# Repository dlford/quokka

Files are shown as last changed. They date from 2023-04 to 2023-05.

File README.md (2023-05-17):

# Quokka Keyboard

Quokka Keyboard PCB

## Features

- Designed for smaller handed folks
  - Steep columnar stagger
  - Slightly tucked in thumb cluster
- Per-key RGB Matrix using the easier to solder SK6812-MINI-E LEDs
- Piezo speakers
- 128x64 OLED displays
- TRRS jack faces back to keep your cables out of the way
- Full duplex serial connection between halves

## Parts List

**\* Affiliate Links**

- 36x MX keys
- 36x [Kailh MX Hot Swap Sockets](https://amzn.to/3pdbQfA)\*
- 36x [D_0805 1N4148 Diodes](https://amzn.to/3pfWarV)\*
- 2x [PJ-320A TRRS Jacks](https://amzn.to/3NHV4iI)\*
- 2x [Adafruit KB2040 MCU](https://www.adafruit.com/product/5302)
- 8x [Stick-on Rubber Feet](https://amzn.to/3HISXHJ)\*
- 2x [PTS636 SP43 LFS Reset Buttons](https://www.digikey.com/en/products/detail/c-k/PTS636-SP43-LFS/10071717) (Optional)
- 36x [SK6812-MINI-E RGB LEDs](https://www.diykeyboards.com/parts/product/sk6812-mini-e-rgb-led) (Optional)
- 2x [GME12864-49 OLED Displays](https://www.littlekeyboards.com/products/128x64-oled-screen) (Optional)
- 2x [KLJ-1102 Piezo Speakers](https://keeb.io/collections/diy-parts/products/piezo-speaker) (Optional)
- [Pin header strip sockets](https://amzn.to/3VFhROo)\* (Recommended, for hot swapping MCUs/OLEDs)
  - Through hole resistors or diodes to sacrifice legs for pin header strip sockets (if using)
- OLED hardware
  - 16x M2x4mm screws
  - 4x M2x10mm stand-offs for OLED mounting
  - 4x M2x15mm stand-offs for OLED covers
- 3D Printed Case hardware
  - 10x M2x9mm screws
  - 10x [M2x3mm heat set inserts](https://www.mcmaster.com/97163A146/)
- Plated Case hardware
  - 20x M2x4mm screws
  - 10x M2x8mm round stand-offs for plate cases ([these stand-offs](https://amzn.to/42FXkLX)\* fit in a 1/8" hole, don't forget a drill and 1/8" drill bit)

## Build Guide

Download the necessary assets from the [releases](https://github.com/dlford/quokka/releases) page, you will find instructions on producing parts there as well.

1.  Lay out two PCBs, make sure one is flipped, as if you were to type on the keyboard.

    \*Note: if you intend to use plates for the case, you will need to carefully drill out the 5 mounting holes on each PCB (marked in green) with a 1/8" drill bit so the stand-offs can fit through the holes (do not drill out the OLED or OLED cover mounting holes marked in red).

    PCB mounting holes to drill out for plated case

2.  Tin SMD Pads

    Add a bit of solder to on leg of the diodes, switches, and LEDs (if using)

    When soldering SMD components, line up the part close to it's mounting place, heat up the solder on the pre-tinned pad, then slide the part in place, hold it there until after solder is cooled (tweezers will help with smaller parts), then solder the remaining legs, and go back over the first leg to ensure a good connection.

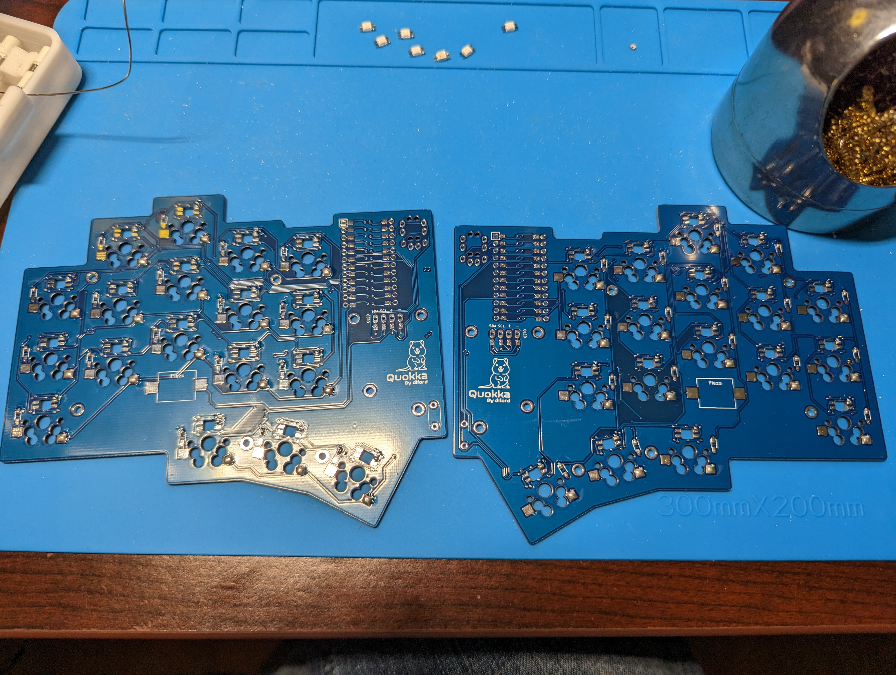
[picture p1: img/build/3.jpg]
SMD Pads Tinned
    

3.  Solder LEDs (if using)

    Place the LEDs _face down_ in the square holes, match the leg with a notch in it to the white triangle on the PCB

    LED orientation, the leg with a notch cut into it matches with the white triangle on the PCB

    LEDs soldered in place

4.  Solder Diodes

    Place the diodes with the stripe facing the top of the keyboard (opposite the thumb keys)

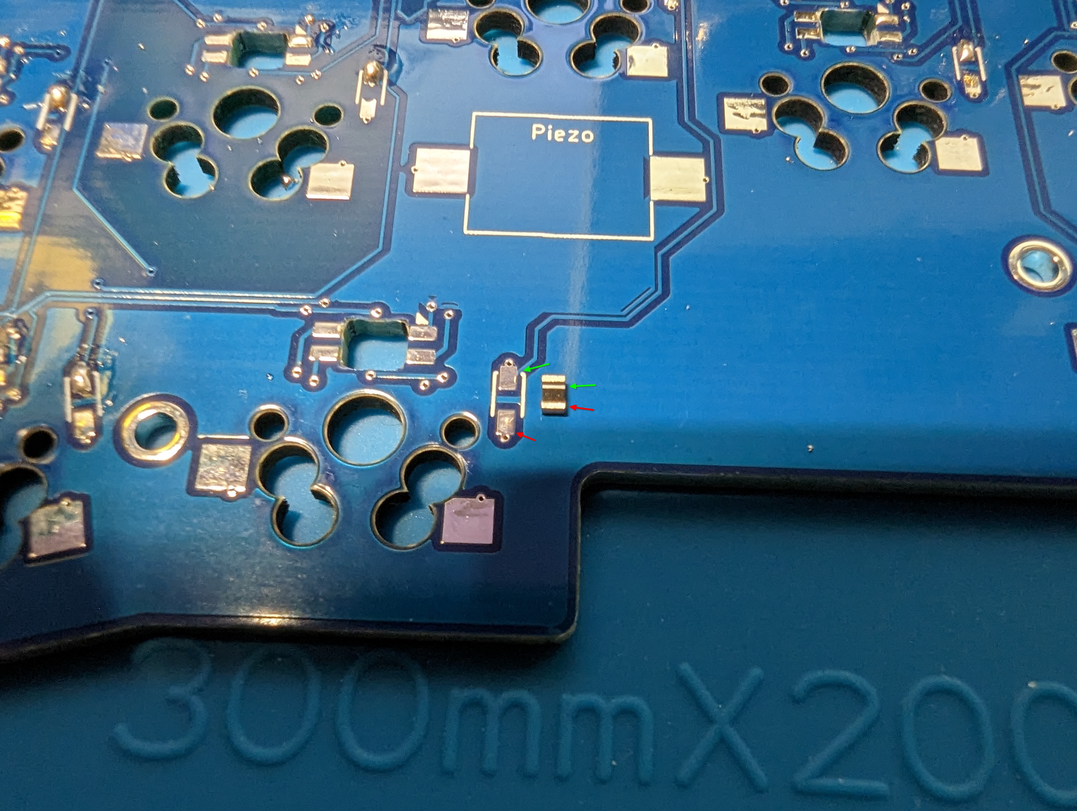
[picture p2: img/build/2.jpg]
Diode orientation
    

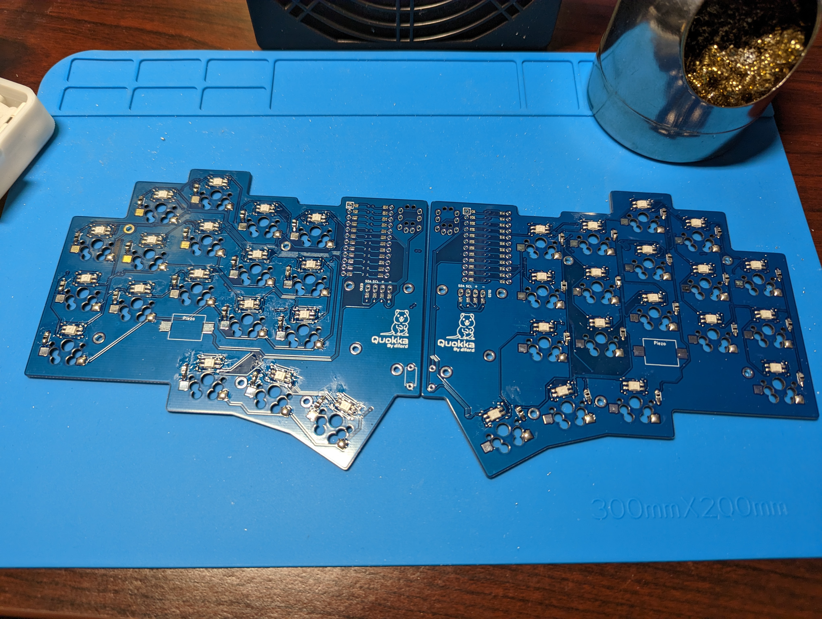
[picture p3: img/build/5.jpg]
Diodes soldered in place
    

5.  Solder Hot Swap Sockets

    Place the sockets so the curved portion is on the left, so as not to cover the center hole for the switch pin

    Hot swap socket orientation

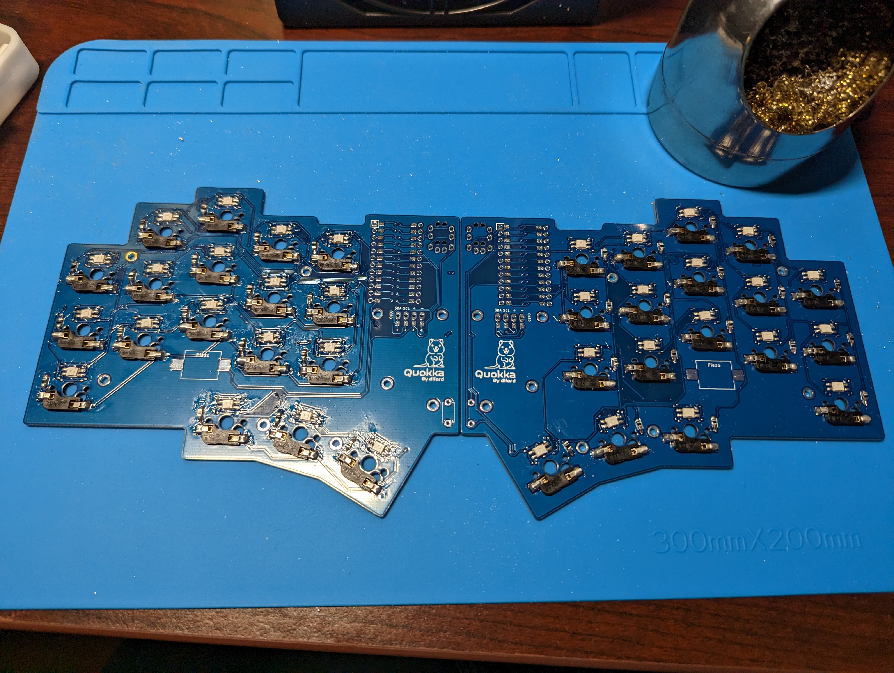
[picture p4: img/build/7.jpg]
Hot swap sockets soldered in place
    

6.  Flip the PCBs over, so everything you just soldered on is on the back, facing the table

7.  Solder the jumpers for the MCU and OLED (if using)

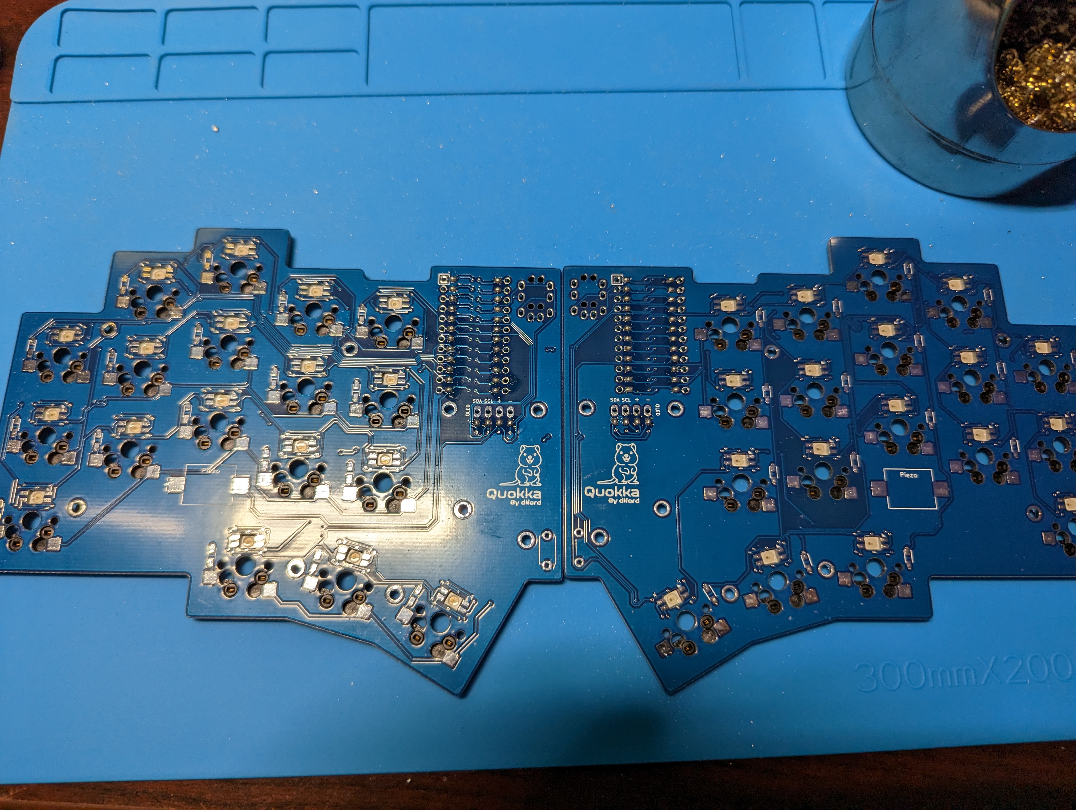
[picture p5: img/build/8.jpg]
Jumpers soldered
    

8.  Solder the TRRS jacks

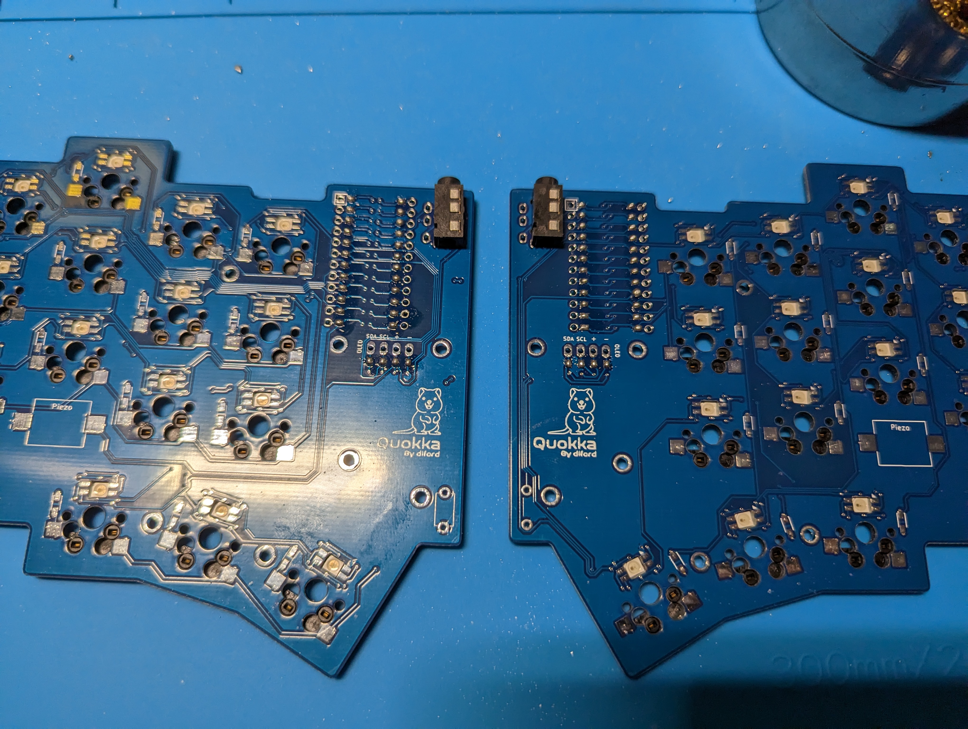
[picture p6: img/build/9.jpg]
TRRS jacks soldered
    

9.  Solder the reset switches

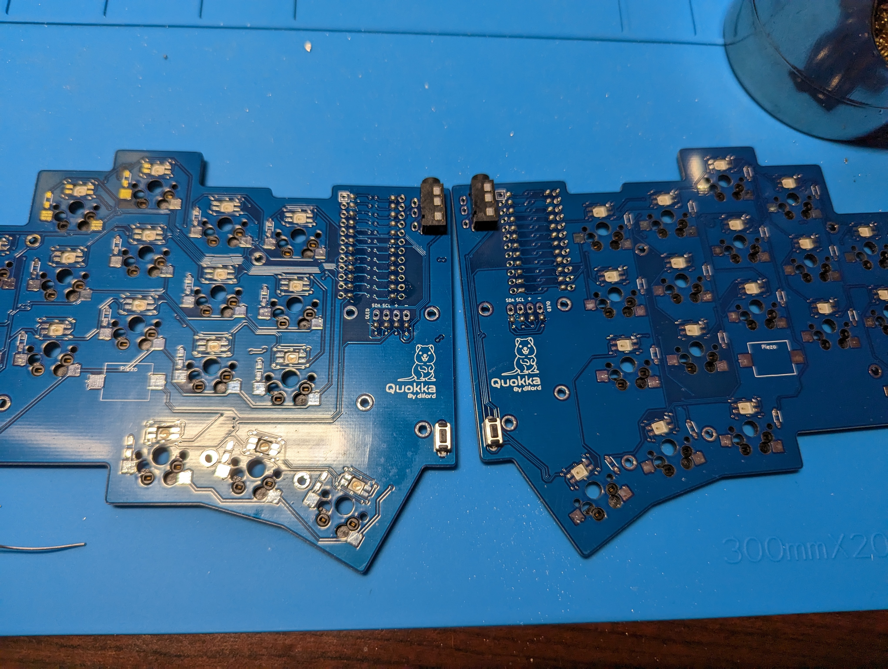
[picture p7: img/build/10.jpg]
Reset switches soldered
    

10. Solder the piezo elements (if using)

    The orientation of piezo elements does not matter

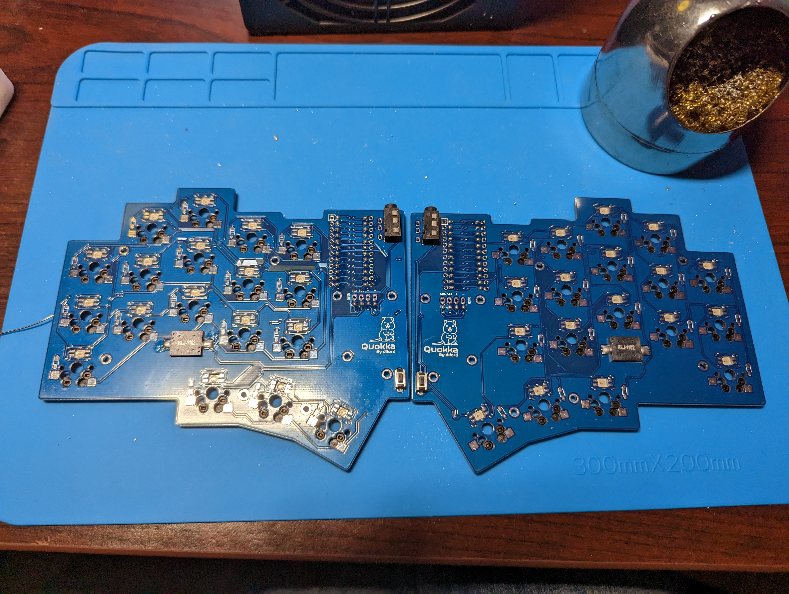
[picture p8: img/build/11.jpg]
Piezo elements soldered
    

11. Solder the header strip sockets for the MCU and OLED (if using)

    After soldering the first leg, heat it back up and adjust the angle of the strip to be as close to vertical as possible

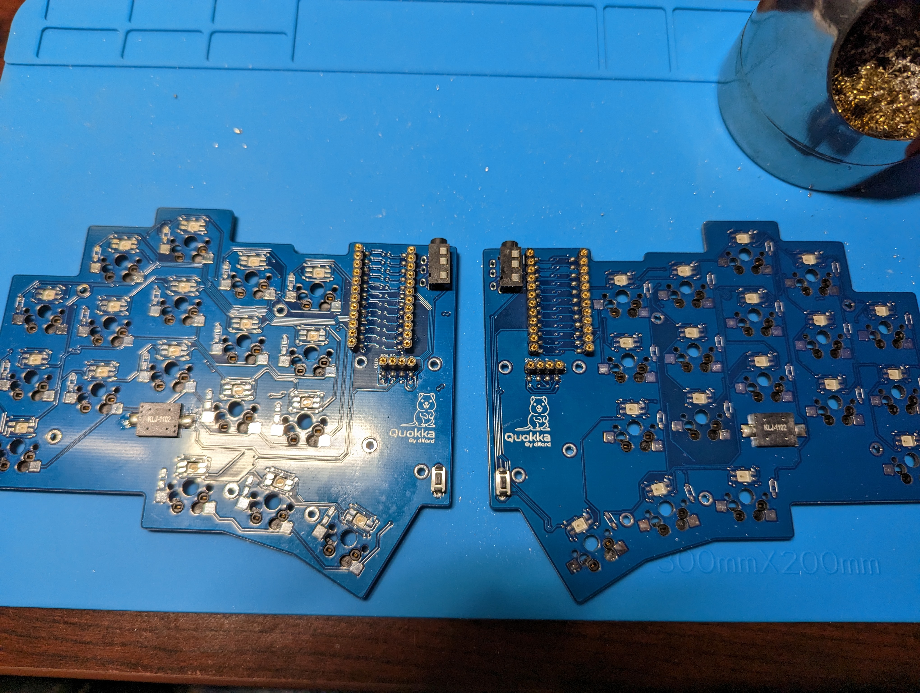
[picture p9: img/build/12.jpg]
Header strip sockets soldered
    

12. Place the MCUs

    Orient the MCUs so they are face up, with the USB-C port facing the back of the keyboard (opposite the thumb keys)

    Use through hole diode or resistor legs to pin down the four corners of each MCU, you should feel some resistance before they drop into the socket, then they will feel snug. Solder down the four corners first.

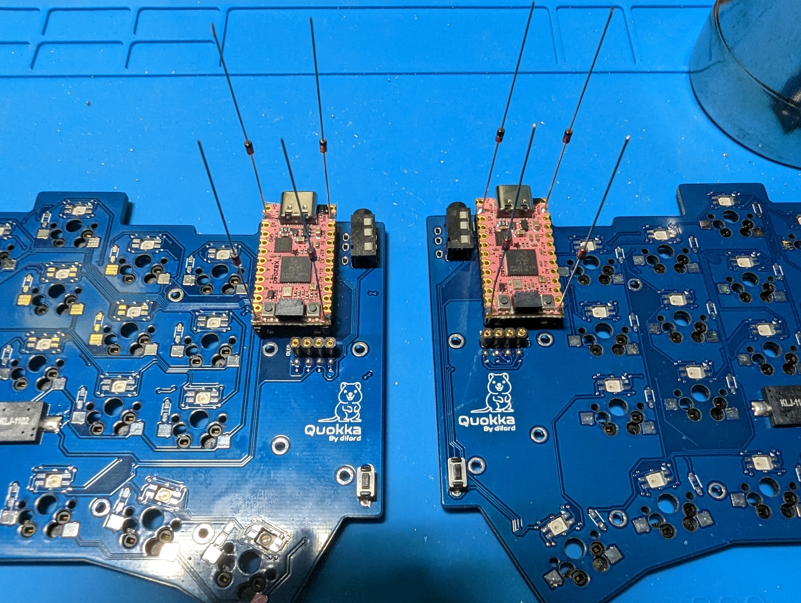
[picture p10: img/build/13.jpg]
MCUs placed
    

    Note that the two contacts closest to the USB-C port on the KB2040 are not used here (also, you may paint black over the power LEDs like I did here, they are quite bright)

    MCU unused contacts

    Cut the diode or resistor legs above the solder joint, and continue soldering each leg the same way

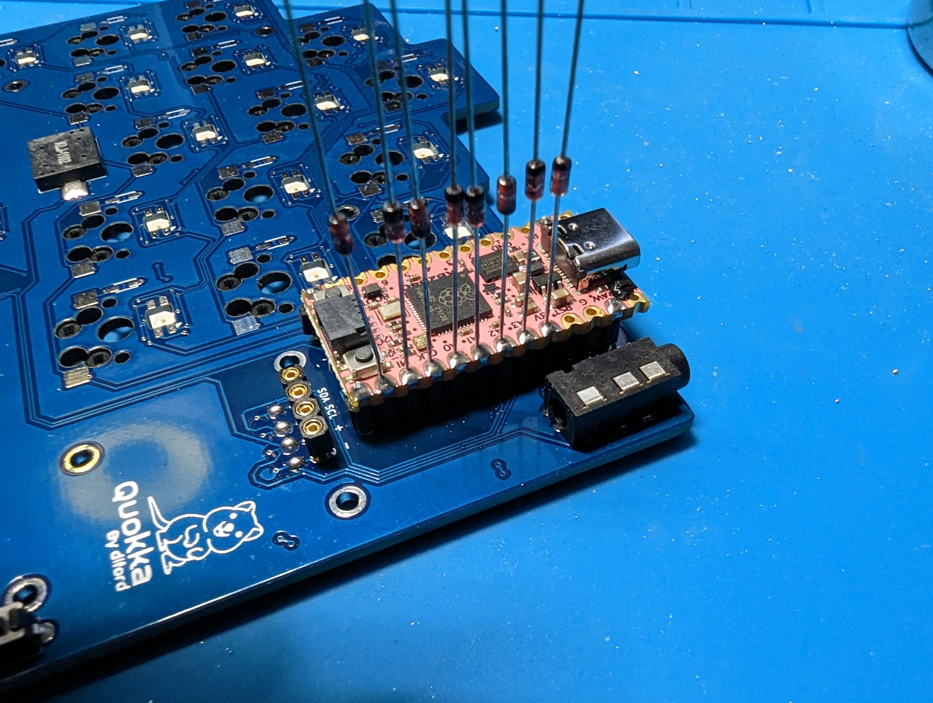
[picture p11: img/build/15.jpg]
MCU contacts soldering process
    

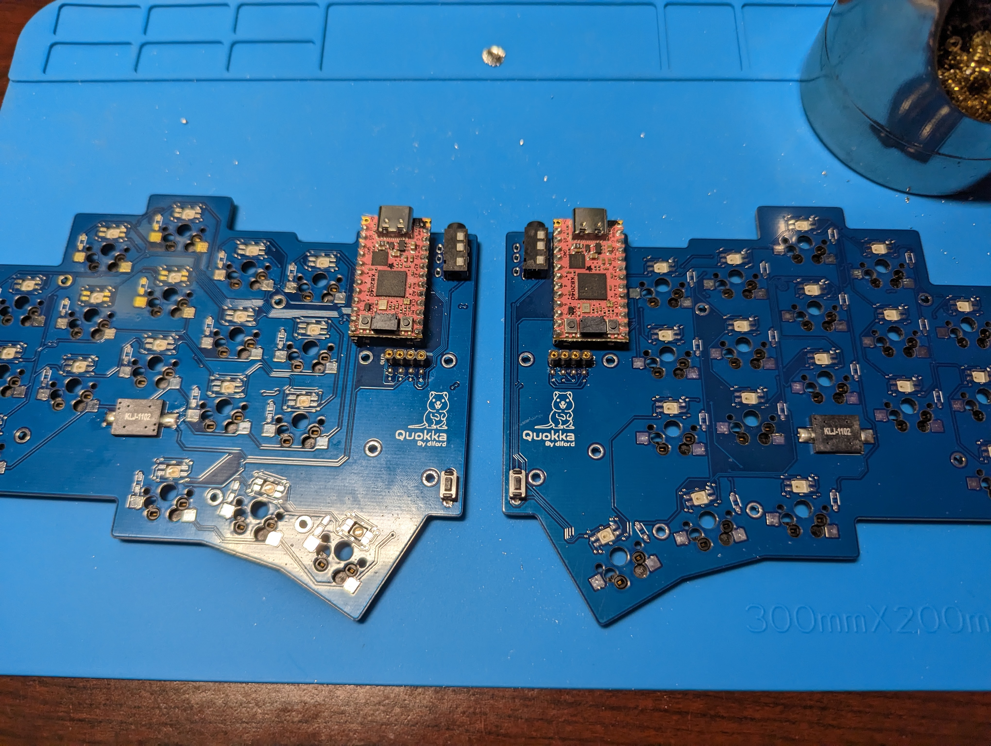
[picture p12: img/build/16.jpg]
MCUs soldered in place
    

13. Now is a good time to flash your MCUs, since the boot button will be covered by the OLEDs later on. After the initial flash, they can be put into bootloader mode by double clicking the reset switch (configured by the QMK options `RP2040_BOOTLOADER_DOUBLE_TAP_RESET` and `RP2040_BOOTLOADER_DOUBLE_TAP_RESET_TIMEOUT` in `config.h`)

14. Install OLEDs (if using)

    Install M2x10mm stand-offs in the two holes in line with the OLED header strip sockets

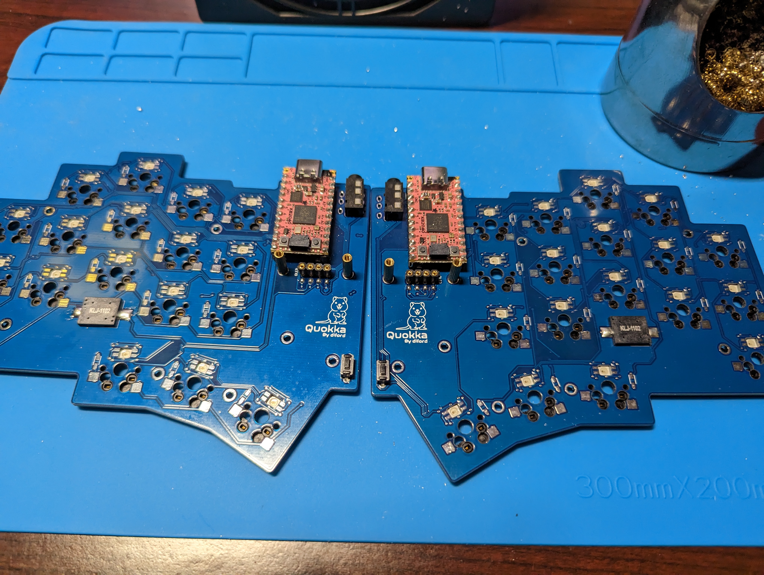
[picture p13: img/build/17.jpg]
OLED mounting standoffs
    

    Screw the OLEDs to the stand-offs but leave them loose for now

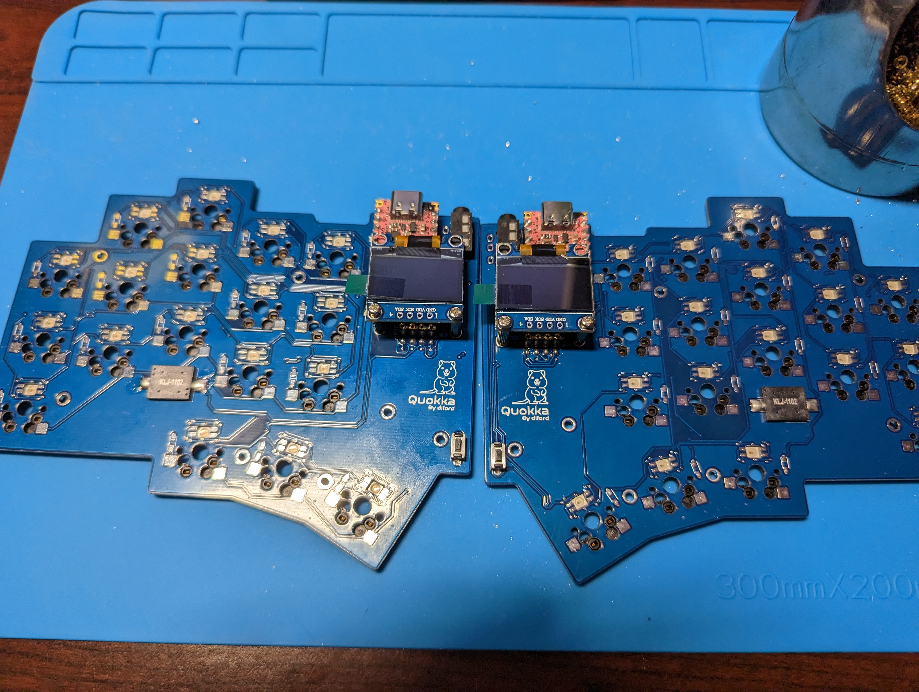
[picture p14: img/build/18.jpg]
OLED loosely attached
    

    Push more diode or resistor legs into the OLED header strip sockets

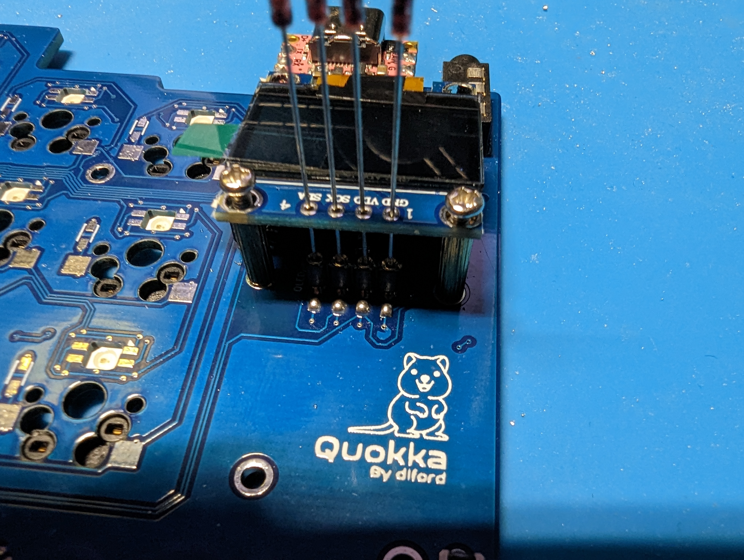
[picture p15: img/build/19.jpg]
OLED pins installed
    

    Now tighten the OLED mounting screws, keeping it as straight as possible

    OLED screws tightened

    Solder and cut the pins

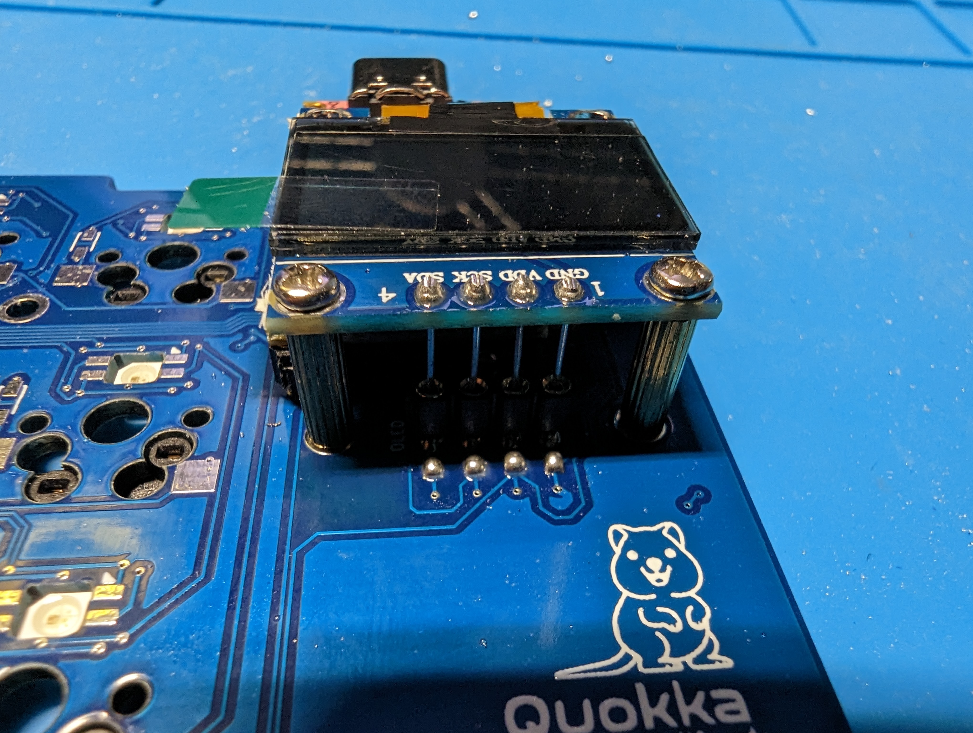
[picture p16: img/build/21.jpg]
OLED installed
    

15. Install OLED covers

    Install M2x15mm stand-offs into the OLED cover mounting holes

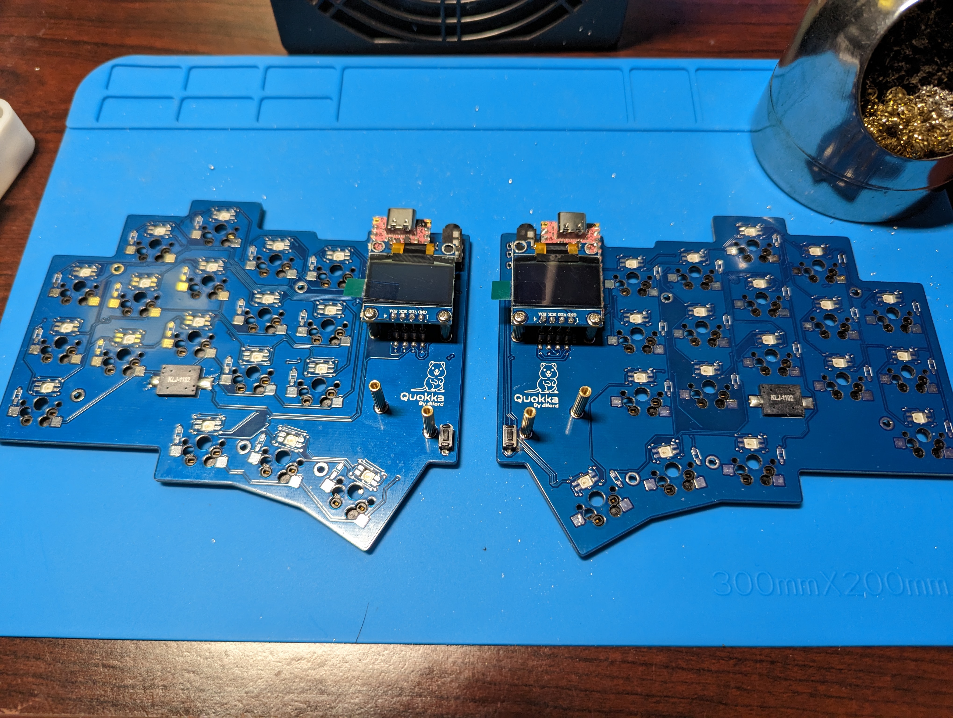
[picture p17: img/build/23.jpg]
OLED cover stand-offs
    

    Install the OLED covers onto the standoffs

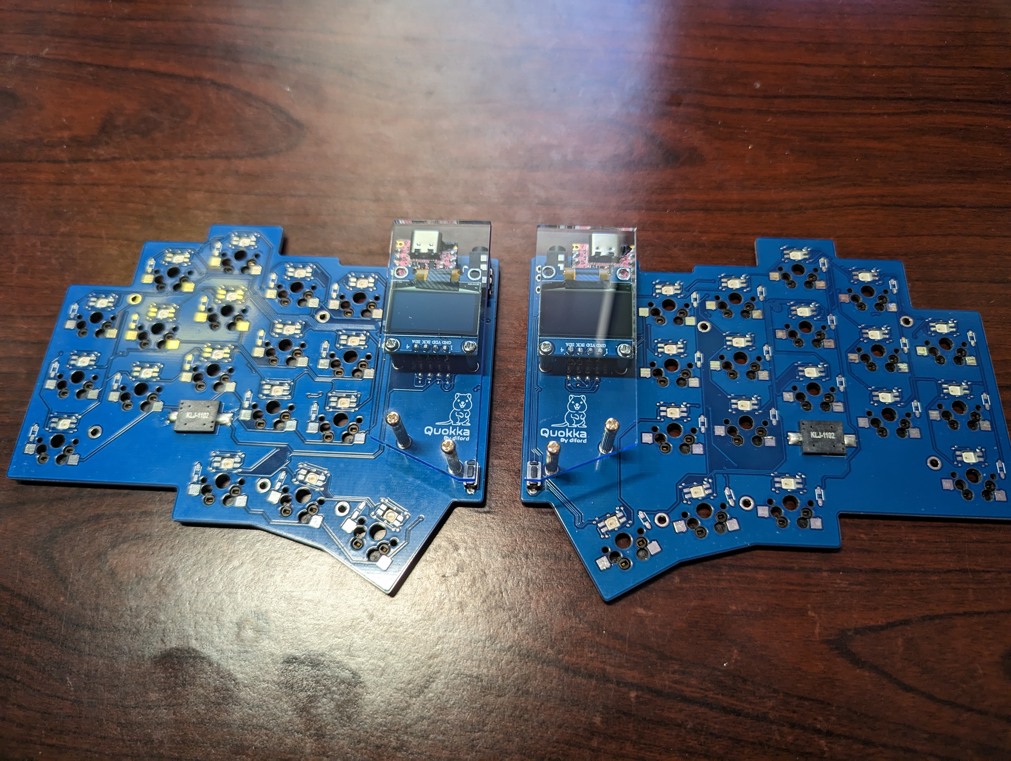
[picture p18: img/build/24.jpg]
OLED cover installed
    

16. Case options

    - No Case

      The easiest option, just stick some rubber feet to the bottom of the PCBs and call it a day

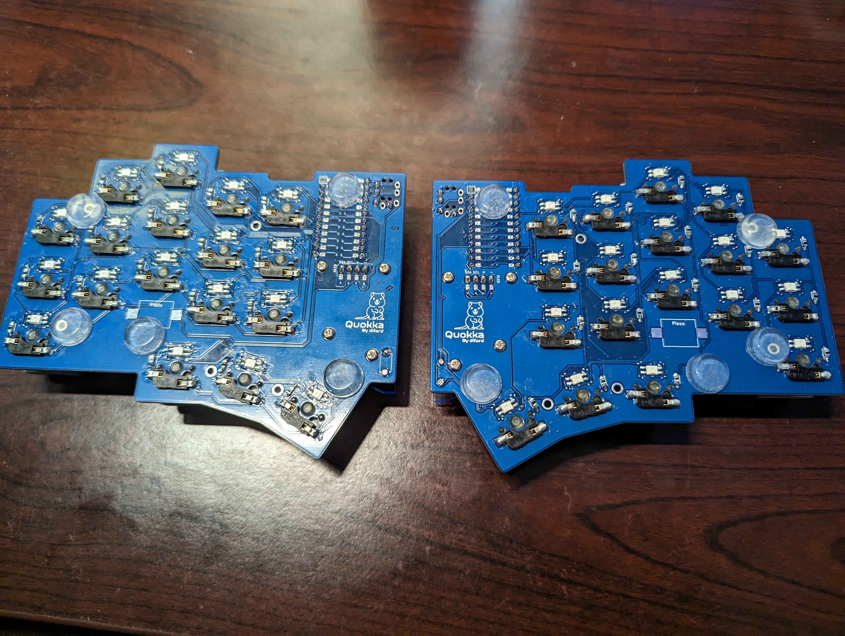
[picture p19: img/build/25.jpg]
Rubber feet on PCB
      

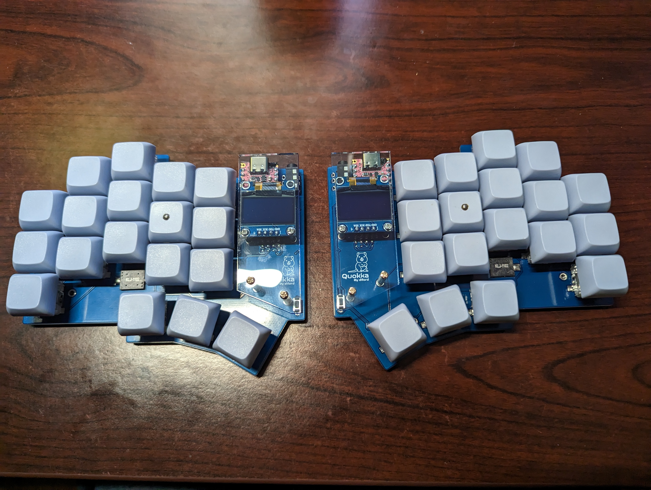
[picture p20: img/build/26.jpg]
No case keyboard finished
      

    - 3D Printed Case

      1. Print or order the parts

      2. Install the heat set inserts into the bottom of the case body parts, careful not to push too deep as they will go right through the case.

      3. Sand and paint the case, if desired

      4. Place the PCB into the case body

      5. Place an M2x9mm screw into each of the holes in the plate, then push a spacer on the the screw from the bottom of the plate

      6. Place the plate over the PCB and tighten each screw

      7. Install your switches

      8. Stick some rubber feet on the bottom of the case

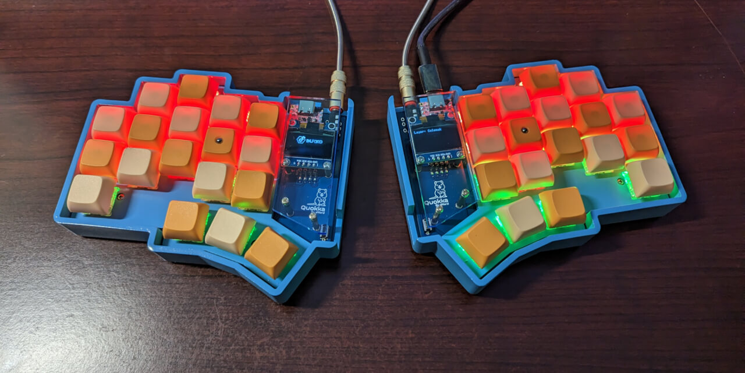
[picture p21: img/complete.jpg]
Quokka Keyboard
      

    - Plated Case

      _Note: If using the 3D printed plate spacers, assemble without switches and install them last, using the bottom spacer with the wide end against the bottom plate, and the top spacer with the wide end against the PCB._

      1. Install M2x8mm stand-offs on the bottom of the plates in the mounting holes

      2. Install a switch into each corner of the plates

      3. Install the PCB onto the switches in the plate

      4. Install the remaining switches

      5. Install the bottom plate on the stand-offs

      6. Stick some rubber feet on the bottom plate

      Shown here using Aluminum plates from [Ponoko](https://ponoko.com), though I would recommend using FR4 plates, or deburred and anodized aluminum plates from [sendcutsend.com](https://sendcutsend.com) for less money

      Plate stack build

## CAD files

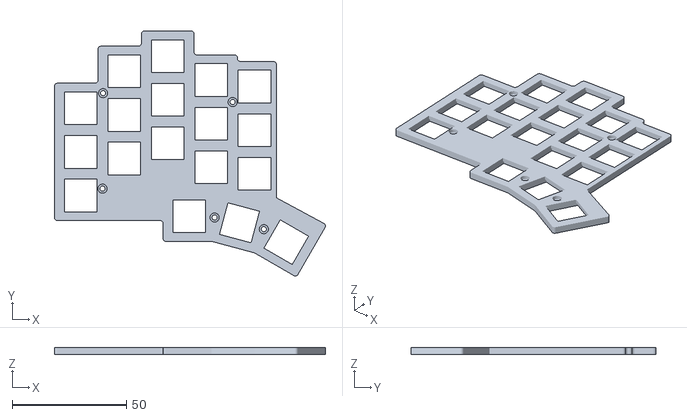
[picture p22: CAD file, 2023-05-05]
3D Case/3d_case_plate.stl
118.5 x 107.2 x 3.00

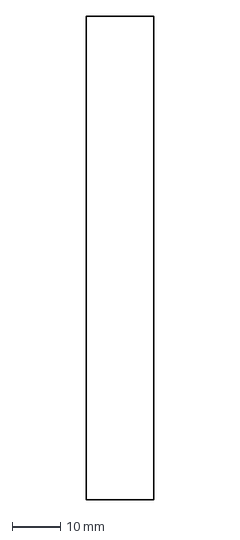
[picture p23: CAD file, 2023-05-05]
3D Case/src/3d_case_port_trrs.dxf
14.0 x 100.0 mm

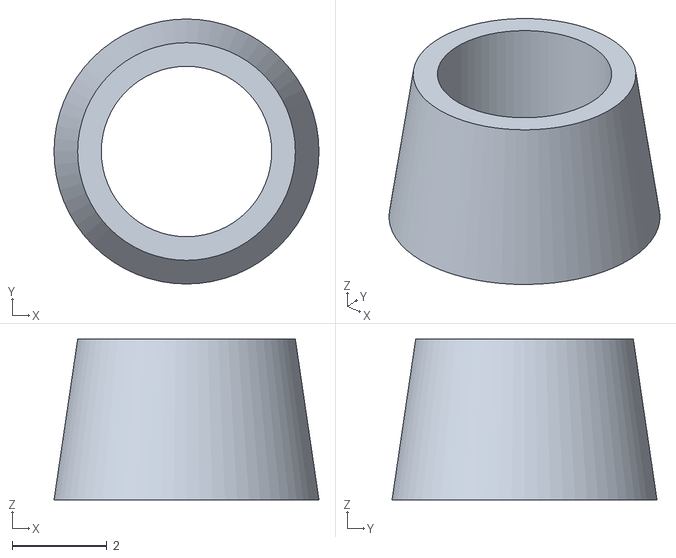
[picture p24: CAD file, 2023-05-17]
Plates/plate_spacer_top.stl
5.60 x 5.60 x 3.40

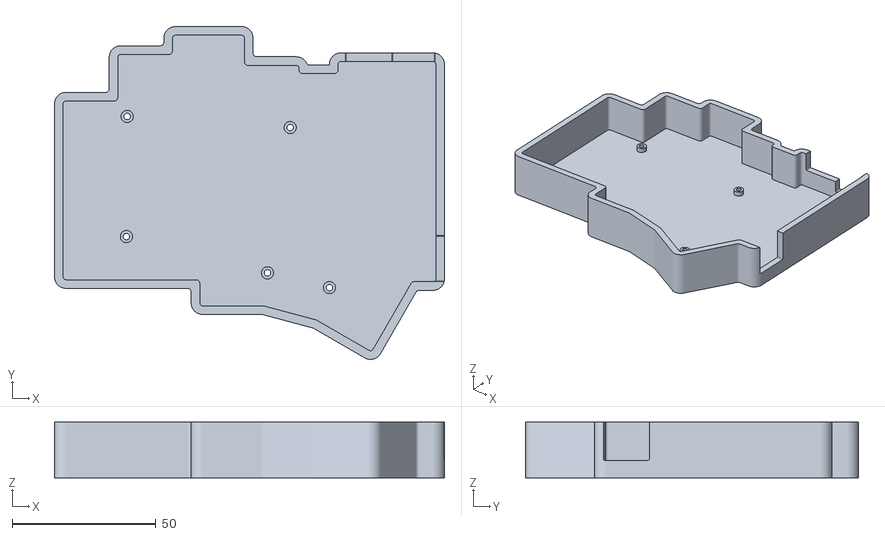
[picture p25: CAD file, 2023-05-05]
3D Case/3d_case_body.stl
135.5 x 115.6 x 19.3

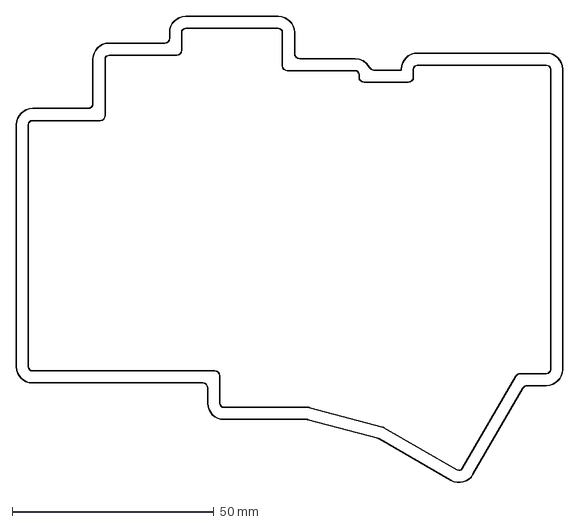
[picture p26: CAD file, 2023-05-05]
3D Case/src/3d_case_wall.dxf
135.5 x 116.2 mm

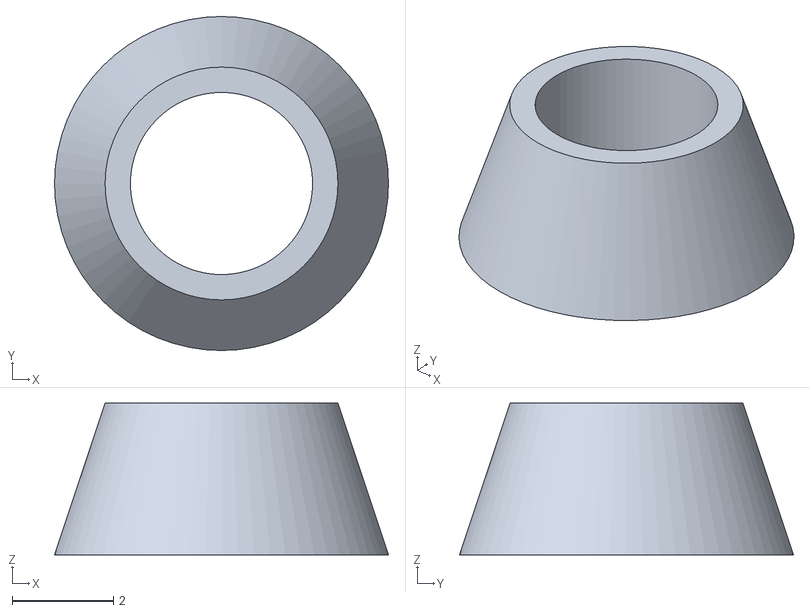
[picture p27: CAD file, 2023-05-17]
Plates/plate_spacer_bottom.stl
6.60 x 6.60 x 3.00

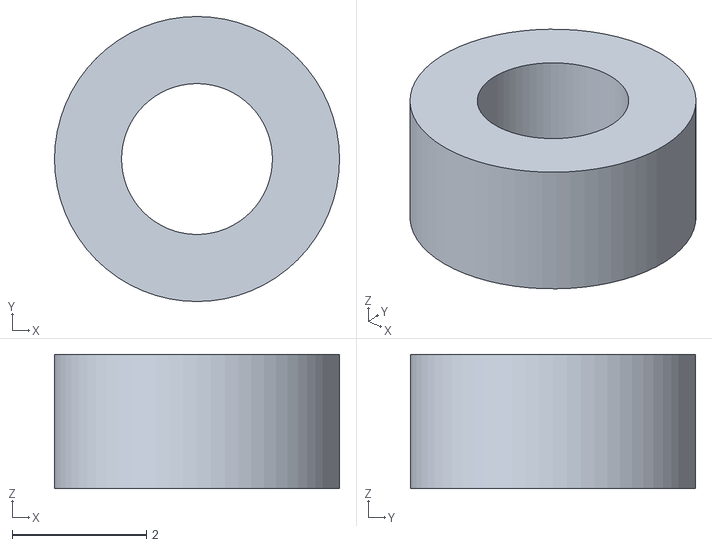
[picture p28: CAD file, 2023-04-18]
3D Case/3d_case_spacer.stl
4.25 x 4.25 x 2.00

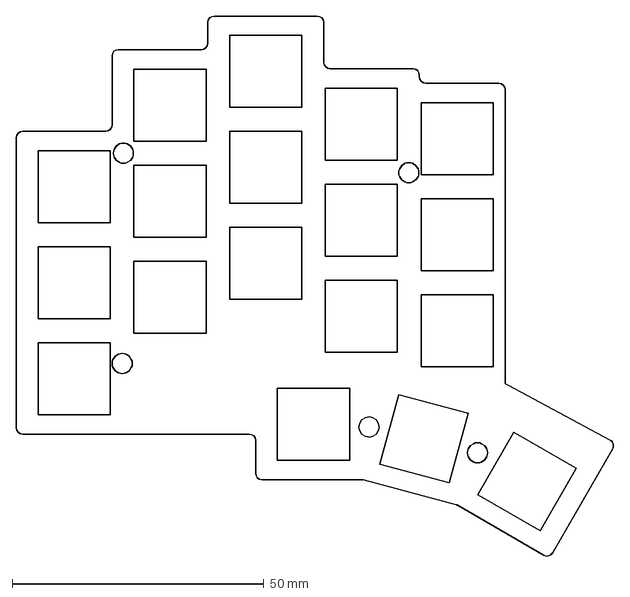
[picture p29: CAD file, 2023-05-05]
3D Case/src/3d_case_plate_upper.dxf
118.6 x 107.4 mm

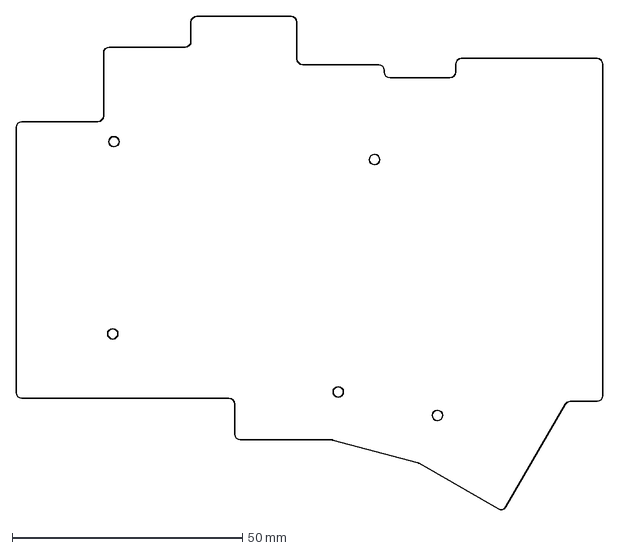
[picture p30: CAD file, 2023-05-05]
Plates/bottom_plate.dxf
127.5 x 107.4 mm

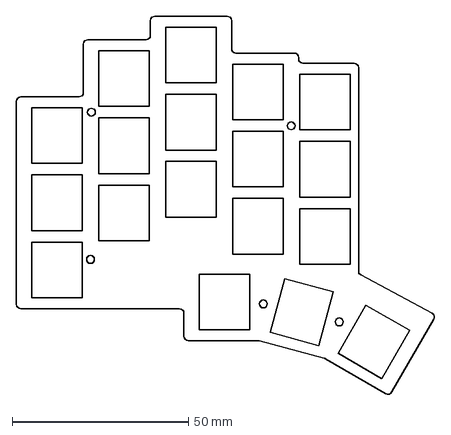
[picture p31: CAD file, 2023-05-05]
3D Case/src/3d_case_plate_lower.dxf
118.6 x 107.4 mm

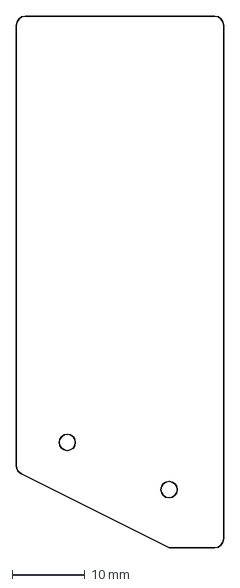
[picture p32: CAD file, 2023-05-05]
Plates/oled_cover.dxf
28.5 x 73.1 mm

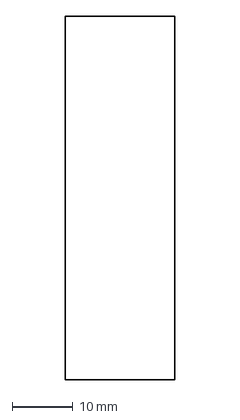
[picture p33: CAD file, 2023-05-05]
3D Case/src/3d_case_port_promicro.dxf
18.0 x 60.0 mm

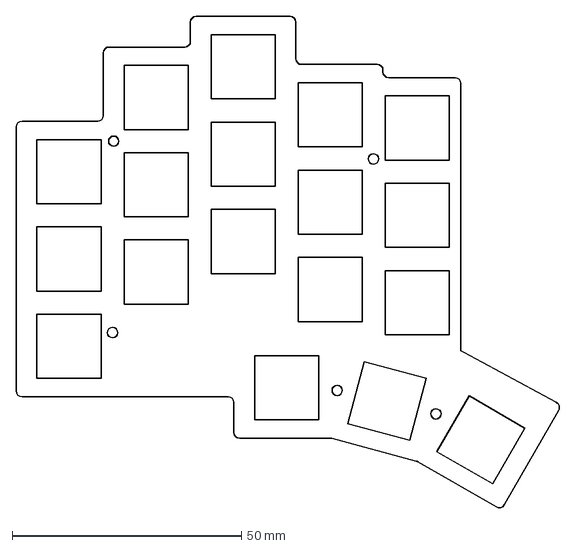
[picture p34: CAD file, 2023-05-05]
Plates/switch_plate.dxf
118.6 x 107.4 mm

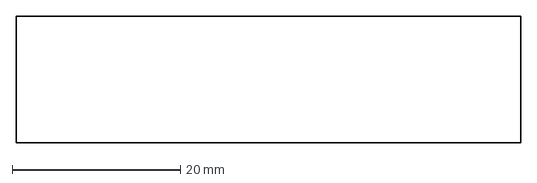
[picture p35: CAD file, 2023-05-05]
3D Case/src/3d_case_port_reset_switch.dxf
60.0 x 15.0 mm

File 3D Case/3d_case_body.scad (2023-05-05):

$fa = $preview ? 1 : 0.01;
$fs = $preview ? 0.1 : 0.01;
$fn = $preview ? 32 : 64;

keycap_bottom_height_from_plate = 7.75;
pcb_thickness = 1.6;
pcb_gap_below = 2;
promicro_height = 12;
promicro_x_offset = 0;
promicro_y_offset = 0;
promicro_z_offset = 5;
trrs_height = 14;
trrs_x_offset = -1.5;
trrs_y_offset = 0;
trrs_z_offset = 0;
reset_switch_height = 20;
reset_switch_x_offset = 0;
reset_switch_y_offset = 0.5;
reset_switch_z_offset = 0;

/* Hidden */
pcb_height = pcb_gap_below + pcb_thickness;
wall_height = pcb_gap_below + pcb_thickness + 5 + keycap_bottom_height_from_plate;

module case_body() {
    linear_extrude(height = 3) {
        import("src/3d_case_base.dxf", dpi = 96);
    }
    translate([0, 0, 3]) {
        linear_extrude(height = pcb_gap_below) {
            import("src/3d_case_pcb_risers.dxf", dpi = 96);
        }
        linear_extrude(height = wall_height) {
            import("src/3d_case_wall.dxf", dpi = 96);
        }
    }
}

module case_ports() {
    translate([promicro_x_offset, promicro_y_offset, promicro_z_offset]) {
        minkowski() {
            linear_extrude(height = promicro_height) {
                import("src/3d_case_port_promicro.dxf", dpi = 96);
            }
            sphere(0.5);
        }
    }
    translate([trrs_x_offset, trrs_y_offset, trrs_z_offset]) {
        minkowski() {
            linear_extrude(height = trrs_height) {
                import("src/3d_case_port_trrs.dxf", dpi = 96);
            }
            sphere(0.5);
        }
    }
    translate([reset_switch_x_offset, reset_switch_y_offset, reset_switch_z_offset]) {
        minkowski() {
            linear_extrude(height = reset_switch_height) {
                import("src/3d_case_port_reset_switch.dxf", dpi = 96);
            }
            sphere(0.5);
        }
    }
}

difference() {
    case_body();
    translate([0,0,pcb_height + 3])
        case_ports();
}

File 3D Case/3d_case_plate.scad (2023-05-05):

$fa = $preview ? 1 : 0.01;
$fs = $preview ? 0.1 : 0.01;
$fn = $preview ? 32 : 64;
 
linear_extrude(height = 1.5) {
    import("src/3d_case_plate_lower.dxf", dpi = 96);
};

translate([0, 0, 1.5]) {
    linear_extrude(height = 1.5) {
        import("src/3d_case_plate_upper.dxf", dpi = 96);
    }
}

/*
linear_extrude(height = 3)
import("/home/dan/git/quokka/output/outlines/oled_cover.dxf");

linear_extrude(height = 3)
import("/home/dan/git/quokka/output/outlines/3d_case_wall.dxf");

translate([0, 0, -3]) {
    linear_extrude(height = 1.5) {
        import("/home/dan/git/quokka/output/outlines/pcb_fillet.dxf");
    }
}
*/

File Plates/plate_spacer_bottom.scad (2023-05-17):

$fa = $preview ? 1 : 0.01;
$fs = $preview ? 0.1 : 0.01;
$fn = $preview ? 32 : 64;

standoff_length = 8;

height = standoff_length - 5;
width = 3.3;

difference() {
    cylinder(height, width, 2.3);
    translate([0,0,-0.1])
    cylinder(6, 1.8, 1.8);
}

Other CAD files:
3D Case/src/3d_case_base.dxf
3D Case/src/3d_case_spacer.dxf
3D Case/src/3d_case_pcb_risers.dxf
3D Case/src/3d_case_switch_cutouts_wide.dxf
3D Case/3d_case_spacer.scad
3D Case/src/3d_case_base_upper.dxf
3D Case/src/3d_case_keycaps.dxf
3D Case/src/3d_case_switch_cutouts.dxf
Plates/plate_spacer_top.scad

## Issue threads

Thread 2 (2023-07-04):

LED Matrix not working

JulioPDX, 2023-07-04:
Hello all,

I'm curious for those that have built this keyboard, were you able to get the LEDs working? I modified one entry to `#define WS2812_DI_PIN F4` and flashed both sides, but no luck. TIA!

JulioPDX, 2023-07-04:
Disregard, I was able to get this working. I'll have to see about adding the best lighting modes. My issue was that my layout was having issues moving to the additional layer with RGB toggles. I modified my layout and was able to change LED settings.

JulioPDX, 2023-07-04:
Thank you

Closed 2023-07-04.

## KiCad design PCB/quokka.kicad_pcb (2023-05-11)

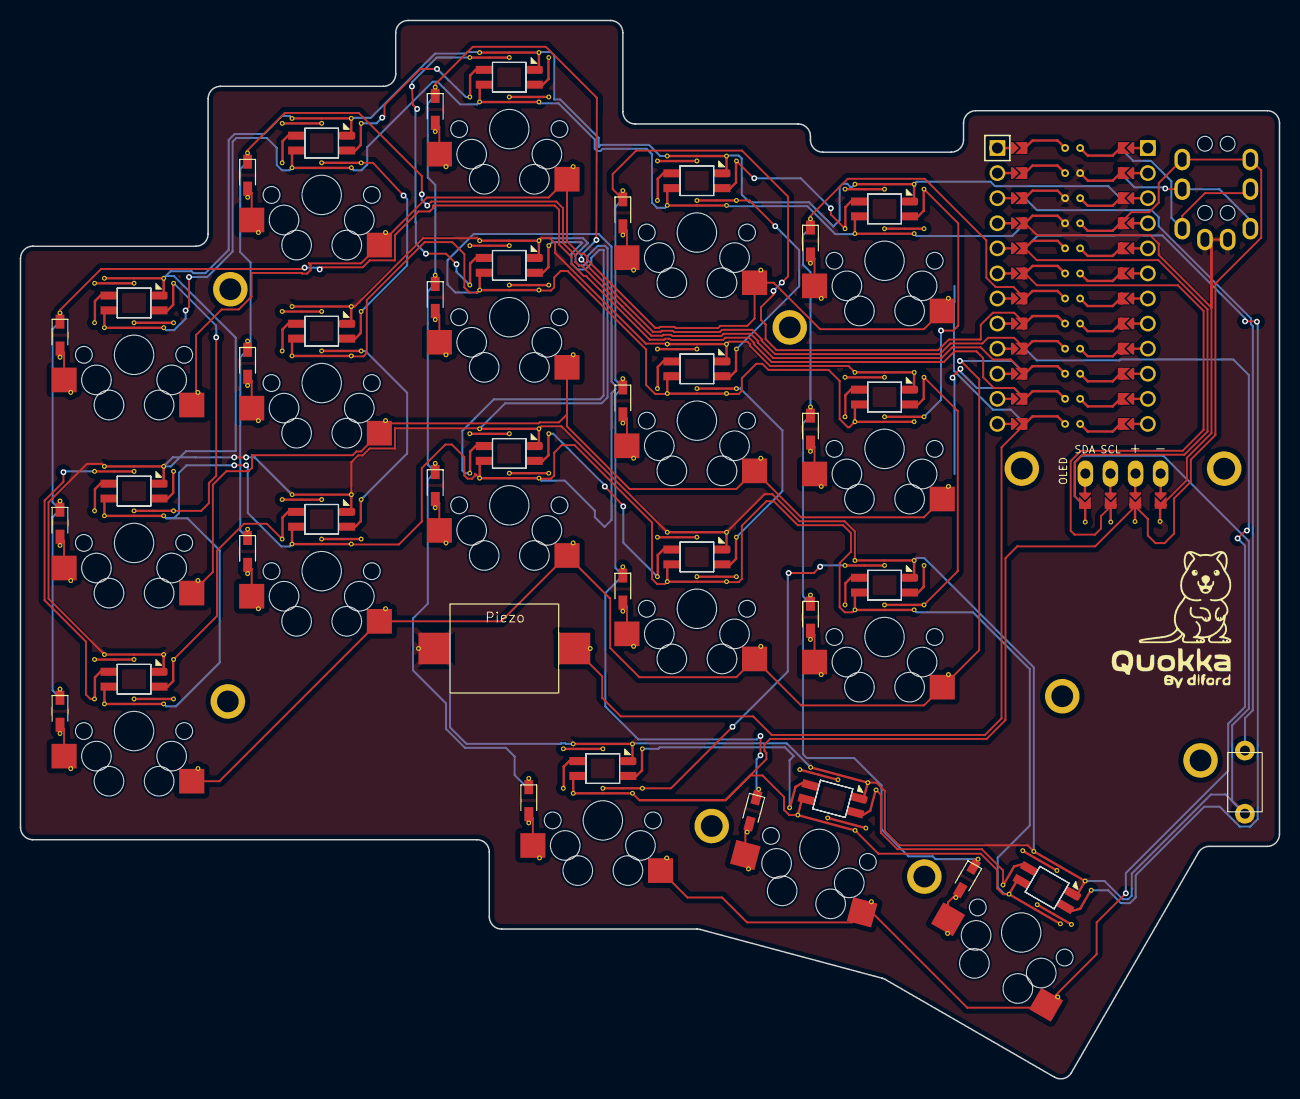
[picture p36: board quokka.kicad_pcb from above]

Board: 2 copper layers, 127.5 x 107.2 mm, 20 parts (0 on the bottom side), 8 nets.

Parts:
MCU1: ProMicro
S1, S2, S3, S4, S5, S6, S7, S8, S9, S10, S11, S12, S13, S14, S15, S16, S17, S18: MX
TRRS1: TRRS-PJ-320A-dual

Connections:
GND: MCU1.2, MCU1.21, MCU1.22, TRRS1.1
P0: MCU1.23, TRRS1.3
P1: MCU1.24, TRRS1.2
P10: MCU1.12, S3.1, S6.1, S9.1, S12.1, S15.1
P14: MCU1.10, S1.1, S4.1, S7.1, S10.1, S13.1
P15: MCU1.9, S16.1, S17.1, S18.1
P16: MCU1.11, S2.1, S5.1, S8.1, S11.1, S14.1
VCC: MCU1.4, TRRS1.4

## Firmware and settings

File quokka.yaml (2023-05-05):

points:
  key:
    bind: 5
  zones:
    matrix:
      columns:
        pinky:
          key:
            bind: [5, 30, 5, 5]
            column_net: P8
        ring.key:
          stagger: 0.85U
          column_net: P7
        middle.key:
          stagger: 0.35U
          bind: [5, 5, 13.5, 5]
          column_net: P6
        index.key:
          stagger: -0.55U
          bind: [5, 5, 5, 10.75]
          column_net: P5
        inner.key:
          stagger: -0.15U
          bind: [5, 30, 12, 5]
          column_net: P4
      rows:
        bottom:
          padding: U
          row_net: P14
        home:
          padding: U
          row_net: P16
        top:
          padding: U
          row_net: P10
    thumb:
      anchor:
        ref: matrix_index_bottom
        shift: [-0.5U, -1.125U]
      columns:
        tucky:
          key:
            name: thumb_tucky
            bind: [8, 12, 5, 5]
            column_net: P6
        home:
          key:
            name: thumb_home
            spread: U
            splay: -15
            origin: [-0.5U, -0.65U]
            column_net: P5
        reachy:
          key:
            spread: U
            splay: -15
            origin: [-0.5U, -0.65U]
            name: thumb_reachy
            bind: [14, 5, 5, 8]
            column_net: P4
      rows:
        thumb:
          row_net: P15

outlines:
  _pcb_raw_keys:
    - what: rectangle
      where: true
      bound: true
      asym: left
      size: [13, 12]
      corner: 1
  _pcb_raw_mcu:
    - what: rectangle
      size: [32, 74.5]
      where:
        - ref: matrix_inner_home
          shift: [24, -3]
  _pcb_raw: [_pcb_raw_keys, _pcb_raw_mcu]
  pcb_fillet:
    - what: outline
      name: _pcb_raw
      fillet: 1.25
  _oled_cover_plate_raw:
    - what: polygon
      points:
        - ref: matrix_inner_top
          shift: [11, 14.5]
        - ref: matrix_inner_bottom
          shift: [11, -10]
        - ref: matrix_inner_bottom
          shift: [32, -20.5]
        - ref: matrix_inner_bottom
          shift: [39.5, -20.5]
        - ref: matrix_inner_top
          shift: [39.5, 14.5]
  _oled_cover_plate:
    - what: outline
      name: _oled_cover_plate_raw
      fillet: 1.25
  _plate_oled_cover_cutout:
    - what: polygon
      points:
        - ref: matrix_inner_top
          shift: [0, 18]
        - ref: matrix_inner_top
          shift: [0, 14]
        - ref: matrix_inner_top
          shift: [0, 11]
        - ref: matrix_inner_top
          shift: [9.5, 11]
        - ref: matrix_inner_bottom
          shift: [9.5, -10.5]
        - ref: matrix_inner_bottom
          shift: [34.5, -24]
        - ref: matrix_inner_bottom
          shift: [41, -35]
        - ref: matrix_inner_top
          shift: [41, 18]
  _plate_with_oled_cutout: [_pcb_raw, -_plate_oled_cover_cutout]
  _plate_fillet:
    - what: outline
      name: _plate_with_oled_cutout
      fillet: 1.25
  _switch_cutouts:
    - what: rectangle
      where: true
      size: 14
      bound: false
  _screw_holes:
    top_left:
      what: circle
      radius: 1.125
      where:
        ref: matrix_ring_home
        shift: [-9.25, 9.5]
    bottom_left:
      what: circle
      radius: 1.125
      where:
        ref: matrix_pinky_bottom
        shift: [9.5, 3]
    top_right:
      what: circle
      radius: 1.125
      where:
        ref: matrix_inner_top
        shift: [-9.6, -6.75]
    palm:
      what: circle
      radius: 1.125
      where:
        ref: matrix_index_bottom
        shift: [1.5, -22]
    thumb:
      what: circle
      radius: 1.125
      where:
        ref: thumb_reachy
        shift: [-11.325, 0]
  _oled_screw_holes:
    bottom_left:
      what: circle
      radius: 1.125
      where:
        ref: matrix_inner_bottom
        shift: [18, -6]
    bottom_right:
      what: circle
      radius: 1.125
      where:
        ref: matrix_inner_bottom
        shift: [32, -12.5]
  _pcb_outline: [pcb_fillet]
  _3d_case_base_raw:
    - what: outline
      name: _pcb_raw
      expand: 4
      fillet: 1.25
  _3d_case_wall_inner:
    - what: outline
      name: _pcb_raw
      expand: 1
      fillet: 1.25
  _screw_holes_counter_sunk:
    $extends: outlines._screw_holes
    top_left:
      radius: 2
    bottom_left:
      radius: 2
    top_right:
      radius: 2
    palm:
      radius: 2
    thumb:
      radius: 2
  _3d_case_holes_heat_set:
    $extends: outlines._screw_holes
    top_left:
      radius: 1.55
    bottom_left:
      radius: 1.55
    top_right:
      radius: 1.55
    palm:
      radius: 1.55
    thumb:
      radius: 1.55
  _3d_case_spacer_outer:
    - what: circle
      radius: 2.125
      where:
        ref: matrix_inner_bottom
        shift: [-20, -20]
  _3d_case_spacer_inner:
    - what: circle
      radius: 1.125
      where:
        ref: matrix_inner_bottom
        shift: [-20, -20]
  _3d_case_pcb_risers_outer:
    $extends: outlines._screw_holes
    top_left:
      radius: 2.125
    bottom_left:
      radius: 2.125
    top_right:
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

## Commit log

2023-04-13 add diodes
2023-04-13 add reset button
2023-04-13 add leds
2023-04-14 add vias for piezo and leds
2023-04-14 remove tht on diodes, add vias
2023-04-14 add din/dout led vias
2023-04-14 rotate switches
2023-04-14 moving vias to footprints
2023-04-14 replace diodes with 0805 footprint
    [quokka.yaml]
2023-04-15 pre-via/trace leds, piezo, diodes
2023-04-15 pre-via mx switches
2023-04-15 fix pinout collision, start on reversable oled
    [quokka.yaml]
2023-04-15 progress on case design
2023-04-15 swap out / shuffle TRRS and reset switch
    [quokka.yaml]
2023-04-15 fine tune screw holes, oled cover
2023-04-15 add oled mounting holes
2023-04-15 re-organize files, eject from ergogen
    [bottom_plate.dxf, oled_cover.dxf, split.kicad_pcb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]
2023-04-15 clean up
    [quokka.kicad_pcb, split.kicad_pcb]
2023-04-16 add pcb logo
    [quokka.kicad_pcb]
2023-04-16 routing PCB
    [quokka.kicad_pcb]
2023-04-16 finished tracing PCB
    [quokka.kicad_pcb]
2023-04-16 clean up traces
    [quokka.kicad_pcb]
2023-04-16 remove oled outline
    [quokka.kicad_pcb]
2023-04-16 test PCBs in production
2023-04-18 start on 3d printed case
    [3d_case_base_lower.dxf, 3d_case_base_upper.dxf, 3d_case_body.scad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]
2023-04-18 3d printed case WIP
    [3d_case_body.scad, 3d_case_pcb_risers.dxf, 3d_case_plate_upper.dxf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]
2023-04-19 add polarity markers to silkscreen layers for piezo
    [quokka.kicad_pcb]
2023-05-02 fix: rgb matrix traces overlapping in two places
    [quokka.kicad_pcb]
2023-05-05 reshape case and PCB
    [3d_case_base.dxf, 3d_case_body.scad, 3d_case_body.stl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]
2023-05-05 re-wire TRRS jacks for full duplex serial connection
    [quokka.kicad_pcb]
2023-05-05 add ground planes to PCB
    [quokka.kicad_pcb]
2023-05-05 add silk labels to PCB
    [quokka.kicad_pcb]
2023-05-05 fix: bottom plate wrong dimensions
    [bottom_plate.dxf]
2023-05-11 update GND zone on PCB to cover all empty space
    [quokka.kicad_pcb]
2023-05-17 progress on plate case
    [plate_spacer_bottom.scad, plate_spacer_bottom.stl, plate_spacer_top.scad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]
